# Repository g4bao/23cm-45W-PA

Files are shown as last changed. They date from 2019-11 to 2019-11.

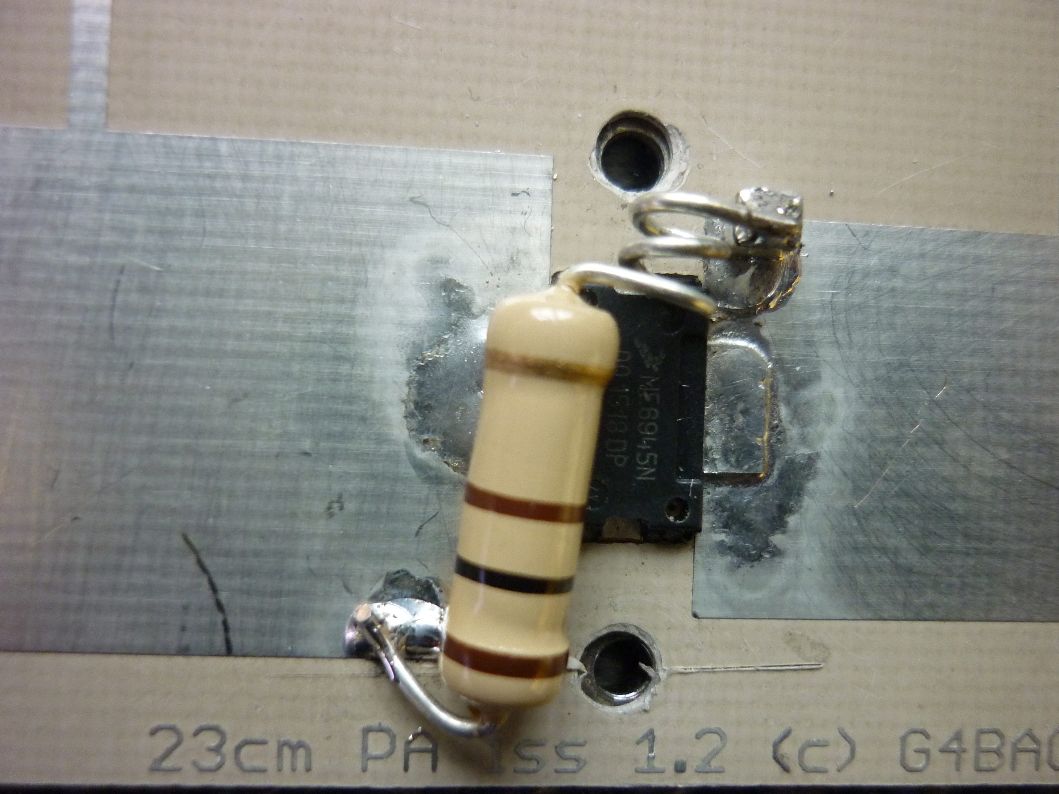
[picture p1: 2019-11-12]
Feedback.JPG

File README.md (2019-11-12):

# 23cm-45W-PA
This repository contains details of the G4BAO 45Watt 23cm Power Amplifier published in RSGB RadCom Magazine in June 2009 and later in the book " Microwave Know How for the Radio Amateur" by Andy Barter, G8ATD

This PA was sold for many years as a kit by the designer. The decision has been made to not sell any further kits so the designs are now made avaialable here under the terms of an MIT licence. 
It includes a copy of the original article, Eagle board and schematic files, plus Gerber files for the PCB, which must be made from  Taconic 0.7mm RF35 substrate.

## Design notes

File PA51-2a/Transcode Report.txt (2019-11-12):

   ---- Transcoding 'F:\Eagle files\projects\23cms PA\Gerbers\PA51-2a\PA51-2a.cmp' ----   Wed Nov 04 16:26:55 2015

D10   --> D100
D11   --> D101
D12   --> D102
D13   --> D103
D14   --> D104
-----------------------------------------------------------------

   ---- Transcoding 'F:\Eagle files\projects\23cms PA\Gerbers\PA51-2a\PA51-2a.pls' ----   Wed Nov 04 16:27:10 2015

D10   --> D105
-----------------------------------------------------------------

   ---- Transcoding 'F:\Eagle files\projects\23cms PA\Gerbers\PA51-2a\PA51-2a.sol' ----   Sat Nov 07 08:40:12 2015

D10   --> D100
D11   --> D101
D12   --> D102
D13   --> D103
D14   --> D104
-----------------------------------------------------------------

   ---- Transcoding 'F:\Eagle files\projects\23cms PA\Gerbers\PA51-2a\PA51-2a.pls' ----   Sat Nov 07 08:43:06 2015

D10   --> D105
-----------------------------------------------------------------

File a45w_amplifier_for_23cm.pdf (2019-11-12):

RADCOM ♦ JUNE 2009 | DR JOHN C WORSNOP, CENG, MIET, G4BAO ♦ E-MAIL: JOHN@G4BAO.COM | TECHNICAL FEATURE

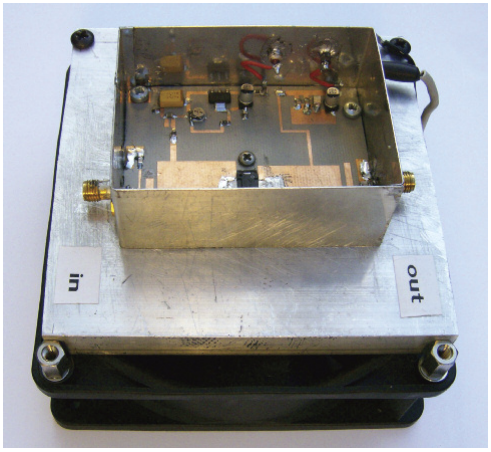
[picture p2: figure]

INTRODUCTION. For many years I operated on 23cm with just 2 watts RF output but never experienced the aircraft scatter and consistent over-the-horizon contacts that I knew the band could support. Increasing the power by 13dB or so opened up the band in ways I didn’t think possible. This article

describes a 45W Class
AB Power amplifier
covering the 1.3GHz
band that requires only
a few watts of drive for
full output. It is a
modern, safe
replacement for a single
2C39A valve amplifier
and does not require a
hazardous high voltage
power supply. It is ideal
for use with a DB6NT
or similar transverter,
a Kenwood TS2000X
or similar transceiver,
reaching a power level
where the 1.3GHz band becomes interesting. The design is very simple and based around a single Freescale [1] MRF9045 28 volt LDMOS device. The PCB is designed to fit in to a readily available 72 x 55 x 30mm tinplate box [2], and should be bolted to a suitable large, heatsink. Alternatively, a smaller heatsink with a fan can be used, as shown in Photo 1. A mini kit consisting of the PCB and MRF9045 is available [3]. This project uses small surface mount devices and requires some experience to construct and set up. It is therefore not suitable for novice constructors.

CIRCUIT DESCRIPTION. Researching designs for the MRF9045 and similar devices it seemed that matching these devices to 50Ω at 1.3GHz requires a relatively simple microstrip network with low impedance (ie wide) lines on the input and output. Half a day playing with Appcad [4] and a Smith chart program [5] allowed me to get a reasonable handle on the required matching networks.
Figure 1 shows the complete circuit diagram. In order to reduce losses, the final circuit avoids using trimmers and shunt capacitors. Device input and output impedances are matched to 50Ω using series low impedance lines TRL2, 4 and 5. ‘Shunt’ lines facilitate the final tuning. The open circuit shunt lines TRL3, TRL6 perform the function of the shunt capacitors of lumped element designs and there is a short circuited shunt line on the input, TRL1, grounded at the end by C5.
The 28 volt supply is connected to the drain via an isolating quarter wave high impedance line, TRL7 and decoupled over a wide range of frequencies by C3, C4, C5 and C6.
Positive gate bias is fed via a similar high impedance line, TRL8, from a 5V regulator and potential divider to set the standing drain current to 350mA. The gate supply is decoupled by C7, C8 and C10. The connection to the gate is via ‘stopper resistor’ R1. This is essential to the design, as it vastly improve low frequency stability of the amplifier. LDMOS devices are remarkably robust but they are susceptible to too much gate voltage. The only time I've destroyed a device during development is when I omitted this resistor. Without gate bias the amplifier takes very little current. Switching the 5V regulator from the press to talk (PTT) line is a convenient way to switch the amplifier in and out of standby, minimising standby power consumption and heat generation.

CONSTRUCTION. The PA is built on a special 0.8mm thick low loss Teflon PCB, the

# A 45W amplifier for 23cm

# LDMOS technology offers easy and

economical microwave power.

PHOTO 1: A prototype 23cm power amplifier fitted to small aluminium heatsink with fins running horizontally. A small black fan gives enough airflow to keep the heatsink cool (Photo: Colin, G8LBS).

TABLE 1 - COMPONENT LIST

Component Value | Type | Farnell reference
R1, R3, R4 820Ω | SMD 0805 | 9334890
R2 | 10k | SMD preset | 1173884
C1, C2, C3 100pF | Np0 ceramic 0805 1414655
C8 | 47pF | Np0 ceramic 1206 1414734
C11 | 47pF | Np0 ceramic 0805 1414692
C4, C7 | 1nF | Np0 ceramic 0805 718567
C5, C9 | 10µF 35V | SMD electrolytic | 8823120
C6 | 100nF | X7 ceramic 0805 | 9406387
C10 | 47µF 16V | SMD electrolytic | 498762
U1 | MRF9045 | LDMOS power FET | www.g4bao.com
U2 | TS2937CW SMD 5V regulator | 7261365
TRL1-8 | Microstrip matching lines on PCB

TECHNICAL FEATURE | JUNE 2009 ♦ RADCOM

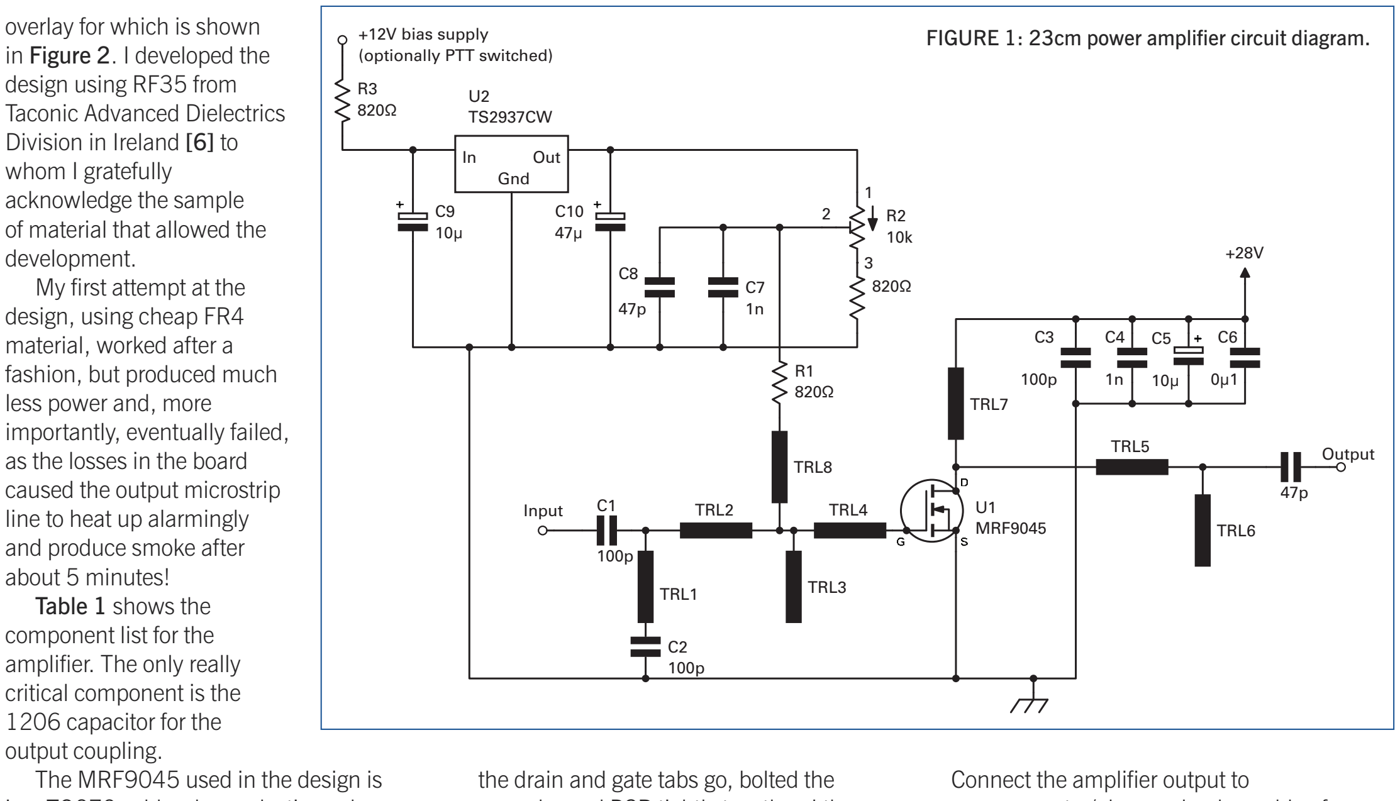
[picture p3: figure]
overlay for which is shown in Figure 2. I developed the design using RF35 from Taconic Advanced Dielectrics Division in Ireland [6] to whom I gratefully acknowledge the sample of material that allowed the development. My first attempt at the design, using cheap FR4 material, worked after a fashion, but produced much less power and, more importantly, eventually failed, as the losses in the board caused the output microstrip line to heat up alarmingly and produce smoke after about 5 minutes! Table 1 shows the component list for the amplifier. The only really critical component is the 1206 capa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

in a TO270 solder-down plastic package. These are now becoming more popular and eliminate the need for hazardous beryllium oxide in the package.
The device is soldered to a piece of copper plate approximately 27mm square and 1mm thick, which acts as a heat spreader between the MRF9045 and the heatsink. (Actually I used one face cut from a piece of waveguide 16). The spreader is soldered to the underside of the PCB and has two holes drilled in it to allow the spreader to be bolted to the heatsink.
Applications note AN1907 [7] from Freescale gives very strict guidelines on temperatures for soldering these devices but I thought, "what the heck, I can’t afford a soldering oven, but I can afford to sacrifice
a couple of devices if it doesn’t work". So I tinned the underside of the PCB, the mating surface of the spreader and the topside where spreader and PCB tightly together. I then dropped the module, spreader side down, on the kitchen ceramic hob, turned it on
and waited for the solder to melt. It duly
did, leaving a shallow ‘pool’ of solder in the rectangular hole in the PCB. I carefully placed the device into the hole, pressing down with the tweezers. I then quickly slid the module off the heat, keeping the pressure on the device until the solder set. Once the device is fitted you can solder in the other components. I have used this technique many times now with no ill effects on the devices. If you have a proper hotplate, all the better; I have now gone ‘upmarket’, using an old dry clothes iron, that I clamp upside down in a vice; that does the trick just as well.
No special precautions or techniques are required for fitting the other components, apart from good microwave practice. Be particularly careful to avoid excess solder, whiskers or excessive flux residues as these can
affect performance.

ALIGNMENT. Bolt the
assembled board and
heat spreader to a large
heatsink. The input and
output matching tabs are
split so that you can
lengthen or shorten them
by bridging them with
solder, if necessary. Start with all the tabs linked for maximum length.
Connect the input from
your 1.3GHz transmitter to the amplifier input via a
suitable SWR meter.

a power meter/ dummy load capable of dissipating and measuring at least 50W. Connect the drain to 28 volts via an ammeter on the 1A range. Connect the gate bias supply, starting with minimum volts on the gate and very carefully increase the gate voltage until the device begins to take current. This onset is very sharp, so be very careful, as the drain current can easily swing up to many amps if you are not careful. Set the drain current to 350mA. Switch off power and then switch the ammeter to the 10A range. Switch back on. Apply 0.5W drive and check the input VSWR. It should be better than about 1.7:1.
If the input VSWR and output power are about right you’re finished, so leave well alone! If not, switch off. Remove one section of one input tab at a time until the VSWR is less than 1.7:1 and check the output power and current. If necessary, trim the output tabs in the same way for maximum power. Do NOT try to make these adjustments with the amplifier operating. Turn up the drive in 3dB steps to 2W and check that the power increases about 3dB each time until it saturates. Now trim the output tab for minimum current consistent with maximum output power. It goes without saying, I hope, that you disconnect both the drain and source bias supplies before you trim the tabs.

RESULTS. Test results for a prototype amplifier are shown in Figures 3 and 4.

CONCLUSIONS. This is an inexpensive PA and is relatively easy to build, with readily available components and produces a useful increase in output power for transverters and transceivers.

FIGURE 1: 23cm power amplifier circuit diagram.

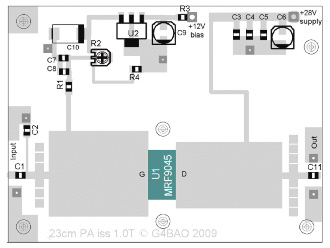
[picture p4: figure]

FIGURE 2: PCB overlay.

RADCOM ♦ JUNE 2009 | TECHNICAL FEATURE

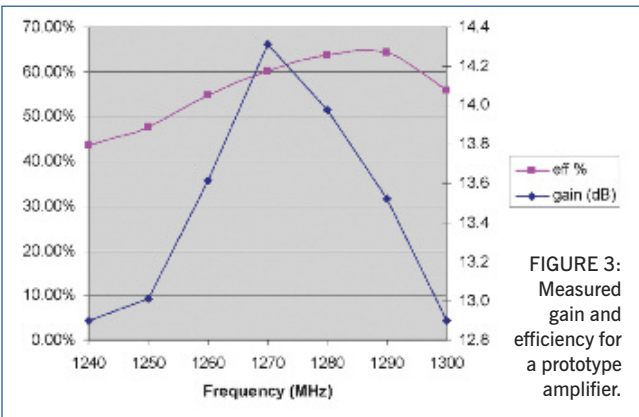
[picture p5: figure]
FIGURE 3: Measured gain and efficiency for a prototype amplifier.

It is efficient and it is safe, in that it does not use any hazardous high voltage supplies. Note, though, it will give you a nasty RF burn if you are silly enough to poke your finger on the output line while transmitting.
It covers the whole of the 1.3GHz narrow band section and, with careful retuning (tabbing), could be adapted to cover the 1240MHz section of the band if band planning eventually forces a move of 1.3GHz narrowband lower in the band.
The amplifier can be made small enough to be masthead mounted, particularly if a fan is fitted, or with a bigger heatsink can be silent for shack use.

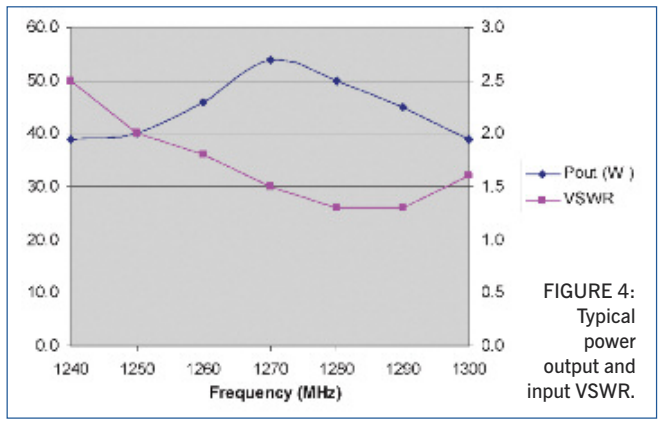
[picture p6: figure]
FIGURE 4: Typical power output and input VSWR.

DEVICE AND PCB AVAILABILITY. A colleague in the US was lucky enough to find a source of ‘new old stock’ MRF9045 LDMOS power transistors in sufficient quantity to make it possible to offer them to constructors. These devices and a PCB will be available shortly, see [3]. I strongly recommend that you do not attempt to make your own PCB, particularly on FR4 laminate, due to the likelihood of catastrophic board failure.

REFERENCES
[1] Freescale applications note AN1907, www.freescale.com/files/rf_if/doc/app_note/ AN1907.pdf
[2] Suitable tinplate boxes can be obtained
from Alan Melia, G3NYK at
www.alan.melia.btinternet.co.uk/componen.htm
[3] PCBs and MRF9045 devices will be available in Europe from www.g4bao.com, and in the Americas from www.wa5vjb.com.
[4] A free and fully functional copy of ‘Appcad’ can be downloaded from www.hp.woodshot.com/ appcad/appcad.htm.
[5] A demo version of ‘Smith’ can be downloaded from www.fritz.dellsperger.net/downloads.htm
[6] Taconic International, Advanced Dielectrics Division, Mullingar Business Park, Mullingar, Co. Westmeath Tel: 00353 (0) 44 9339071, e-mail: add@4taconic.com; www.taconic-add.com
[7] Freescale applications note AN1907, “Solder Reflow Attach Method for High Power RF Devices in Plastic Packages”

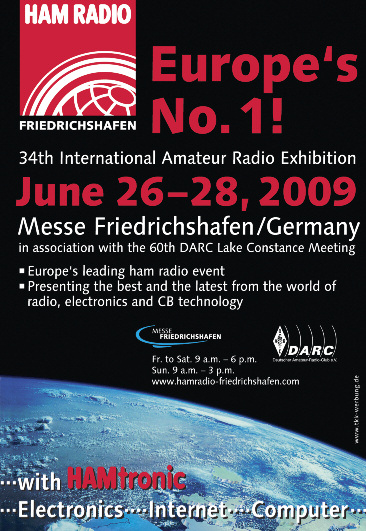
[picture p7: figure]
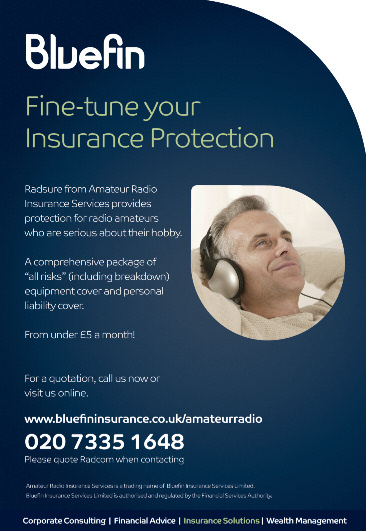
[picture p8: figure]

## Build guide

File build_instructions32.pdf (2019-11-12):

G4BAO 23cm PA build | Issue 3.21 November 2015

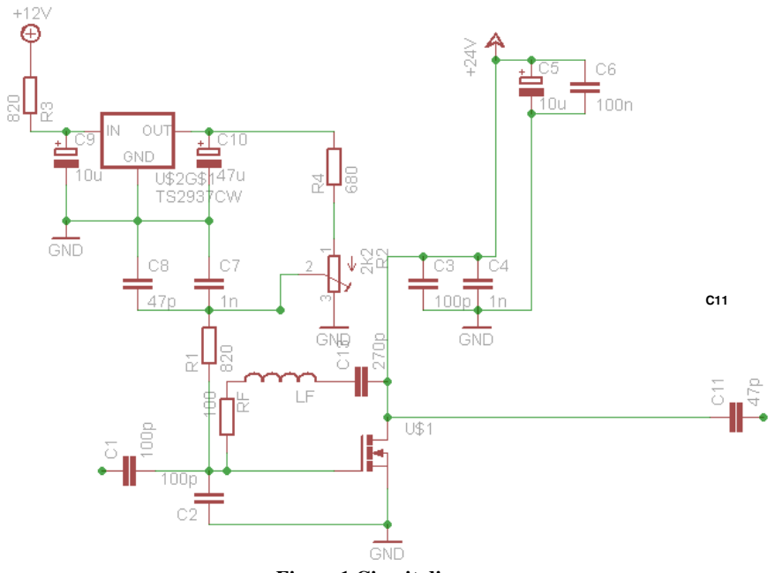
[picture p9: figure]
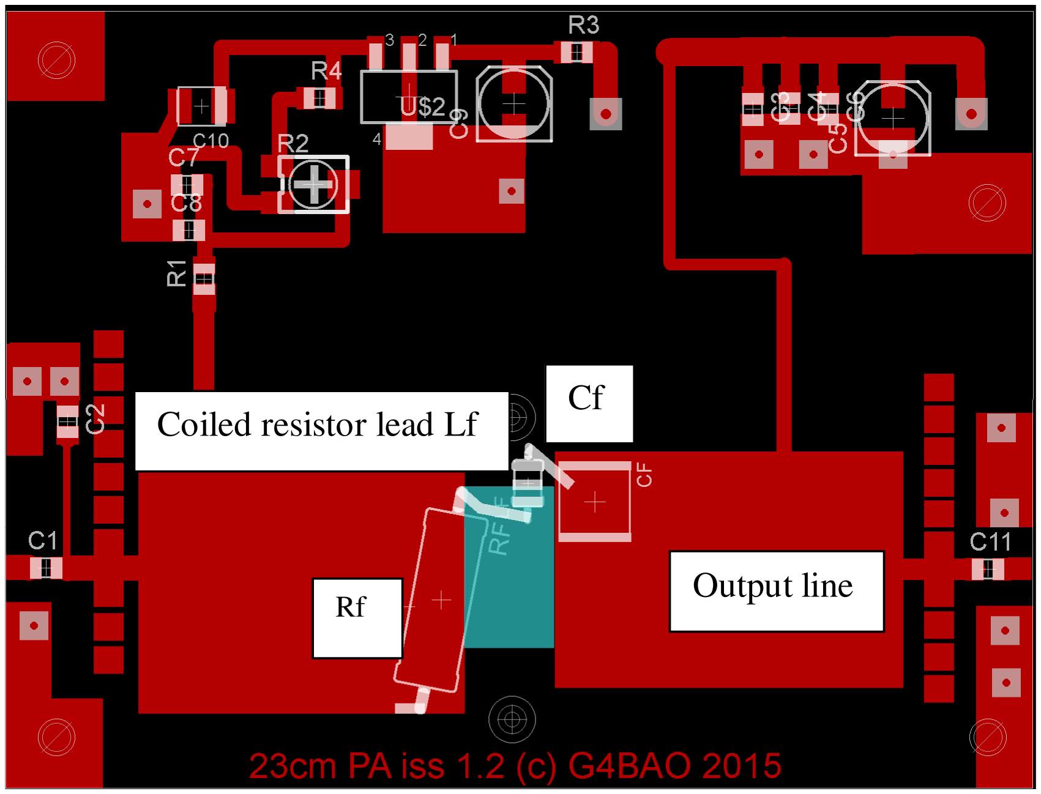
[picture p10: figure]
Coiled resistor lead Lf; Output line

© 2010 Bravo Alpha Oscar | Page 1 | printed 19/12/2015

# 23cm LDMOS Power Amplifier – Assembly notes

This kit contains the components required to build a G4BAO 23cms Power amplifier as described in the June 2009 Issue of RadCom, and includes any updates since publication, particularly the feedback modification, Rf, Cf and Lf. Note that in the original article, the component sizes for C8 and C11 were transposed. Also the names of C5 and C6 have been transposed on the layout diagram. Looking at the board with the 28V pin to the top right, from left to right it goes in increasing value, C3 100pF, C4 1nF, C6 100nF, C5 (electrolytic) 10uF. This document is correct for PCBs purchased after November 15th 2015.

Figure 1 Circuit diagram

Figure 2 PCB layout

© 2010 Bravo Alpha Oscar | Page 2 | printed 19/12/2015

## Antistatic precautions

Note that the LDMOS power FET device fitted to the PCB is still susceptible to static damage until the board has been assembled. Do not remove the tinfoil from the PCB without wearing an antistatic wrist strap or at minimum before having first touched something grounded.

## Component list

Component | Value | Type | Identifier
R1, R3 | 820 | SMD 0805 | Red
R4 | 680 | SMD 0805 | Brown
R2 | 10k | SMD preset | The only preset in the kit!
Rf | 100 ohm | 2 Watt carbon film | Wire ended non- SMD part
C1, C2, C3 | 100pF | Np0 ceramic 0805 | Black and white
C11 | 47pF | Np0 ceramic 1206 | Black and clear plastic
C8 | 47pF | Np0 ceramic 0805 | Green
C4, C7 | 1nF | Np0 ceramic 0805 | Orange
C5, C9 | 10uF 35V | SMD electrolytic | Silver can. Black bar is negative
C6 | 100nF | X7 ceramic 0805 | No marking
C10 | 22 to 47uF 16V OR 10V | SMD Tantalum | Yellow case. Red bar is positive OR Black case, silver bar is positive
Cf | 270pF to 1nF | AVX RF cap | 271 large cube
Lf | | 2 turns of resistor Rf lead on 2.5mm mandrel | Part of Rf
U$1 | MRF9045 or similar | LDMOS power | Attached to PCB
U$2 | 78M05 | SMD 5V regulator | Manufacturer’s mark
PCB pins | Qty 2 | PCB pins | For +12 and +28Volt supplies
Wire | 100mm | 24SWG tinned copper | For tuning.

Check that all the components are present in the kit, and email john@g4bao.com immediately if there is anything missing.

## Tools

Use a small temperature controlled, earthed soldering iron, and thin (28swg) solder. A pair of small sharp side cutters
Small SMD tweezers

## Assembly

Remember throughout assembly that the FET is already fitted to the board so observe antistatic precautions.
The Teflon PCB material is softer that the usual FR4, so do not to bend the PCB once the components are fitted as this can crack the components
For best results, always use the preferred Schuberth tinplate box and follow the assembly notes carefully.

To fit the recommended standard Schuberth box, you just need to "nick" the two diagonal opposite corners of the board to accommodate where the box sides overlap internally.

© 2010 Bravo Alpha Oscar | Page 3 | printed 19/12/2015
1. Fit the +12 and +28Volt pins, soldering top and bottom. They are a tight push fit in to the holes. Take great care to ensure that you do not bridge the solder to ground, especially underneath.
2. Link the all the input and output tuning tabs. Refer to Fig 3 showing how to do this. Put a small blob of solder on all tabs first then tin the end 2mm of the link wire and solder it between the tabs. Then trim the wire off with a sharp scalpel. Do this for each pait of tabs and the input/output lines.
3. Check for shorts to ground on the +12 and +28volt pins Fit the two resistors R3 and 4. DO NOT FIT R1 YET!
4. Fit the eight 0805 ceramic capacitors C1-4, C6, C7, C8, C11.
5. Fit the Preset R2
6. Fit C5, C9 and C10.
7. Fit the 5V regulator.
8. Fit the feedback components RF and Cf as described below
9. Stick a small piece of insulating tape underneath the supply pins, as the solder bulge puts them close to the heatsink when bolted down.

Use exactly the same layout as shown in Photo 1 or poor results will be obtained.
Stand the AVX capacitor “on it’s end” and solder the bottom to the output line first. Tin the other end. The resistor comes ready trimmed and should fit between the input line and the top of the capacitor. Solder the resistor short leg down first, then carefully bend the “coil” end such that it touches the unattached end of Cf. Make sure that the coil lead stays touching the capacitor, and does not “pull” on the end of the capacitor after soldering as it could break it once soldered. You can then solder it to the unattached end of Cf.

Make sure that the coil turns are not shorted, and that neither the capacitor nor the coil shorts to ground, the screws or the PA transistor.

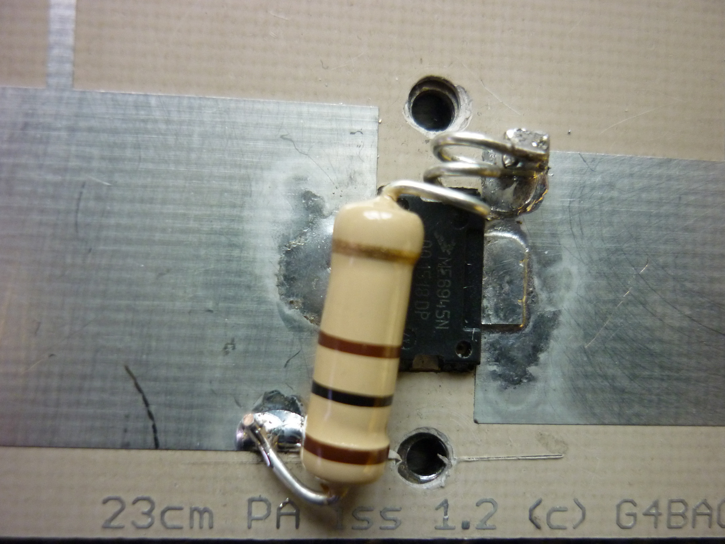
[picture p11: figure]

© 2010 Bravo Alpha Oscar | Page 4 | printed 19/12/2015

## Initial check

RE-CHECK THAT YOU HAVE NOT FITTED R1 YET. If you have, remove it and place it to one side for later!

Be careful with R2, it is possible to increase the bias enough to destroy the device Turning the pot clockwise INCREASES the Bias current/voltage

Check for shorts to ground on the +12 and +28Volt pins

Set R2 to the centre of its travel and apply +12 volts to the 12volt pin, and ground to the ground plane and measure the voltage at the + end of C10. It should read 5 volts +/- 0.2.

Measure the voltage at the junction of C8 where it connects to R1. It should be 2.3V +/- 0.2.

Rotate R20 anticlockwise until the voltage is at minimum. Measure the voltage at the junction of C8 where it connects to R1. It should be 0.0V +/- 0.2.

Leave the preset at this setting and remove the 12 volt supply. Fit R1.

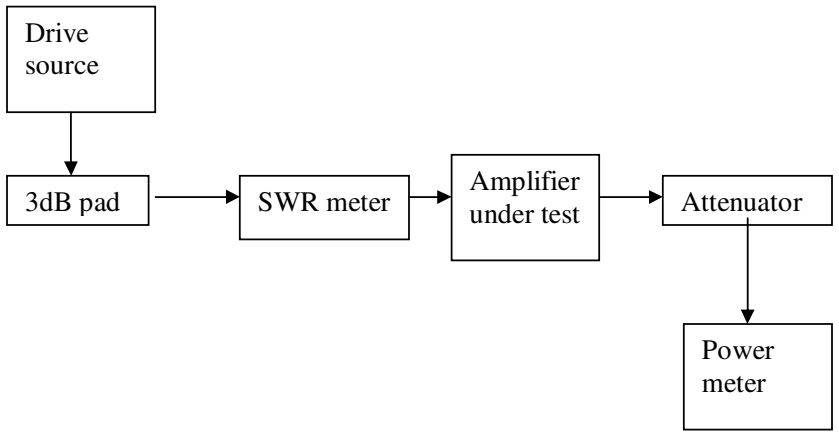
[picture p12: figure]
Drive source; 3dB pad; SWR meter; Amplifier under test; Power meter; Attenuator

© 2010 Bravo Alpha Oscar | Page 5 | printed 19/12/2015

## Recommended Test equipment

Equipment | Example
1.3GHz SWR meter | Bird Thruline or Diamond SX1000
Drive source with adjustable power from 0.5 to 3W | Transceiver/ transverter plus 3dB attenuator
RF power meter and attenuators to measure up to 50Watts | HP 435A, HP436 plus 30 dB attenuator. Bird Thruline or Diamond SX1000 plus 50Watt dummy load.

## Assembly notes

If you are mounting the PCB in the recommended tinplate box, make sure that the tabs for the input and output connectors do not short to the box. If so trim them back 0.5mm with a very sharp scalpel
Where possible align the PCB in its final box to minimise tuning errors due to proximity of the box sides effecting tuning. If using the recommended the Eisch/G3NYK boxes, the PCB should be fitted such that the bottom of the heat spreader plate is flush and level with the bottom of the box sides. This allows the whole box and PCB assembly to be bolted flat on a heatsink using the two screws through the heat spreader. I’ve found that no other fixings are needed. Solder the edges of the ground plane and the topside grounds near input and output to the tinplate box completely round the ground plane side. The two SMA connector centres should be mounted 6mm up the box sides to allow for the SMA plugs to be screwed on. The SMA centre spills should be connected to the PCB with the shortest length of 0.5mm copper wire possible.

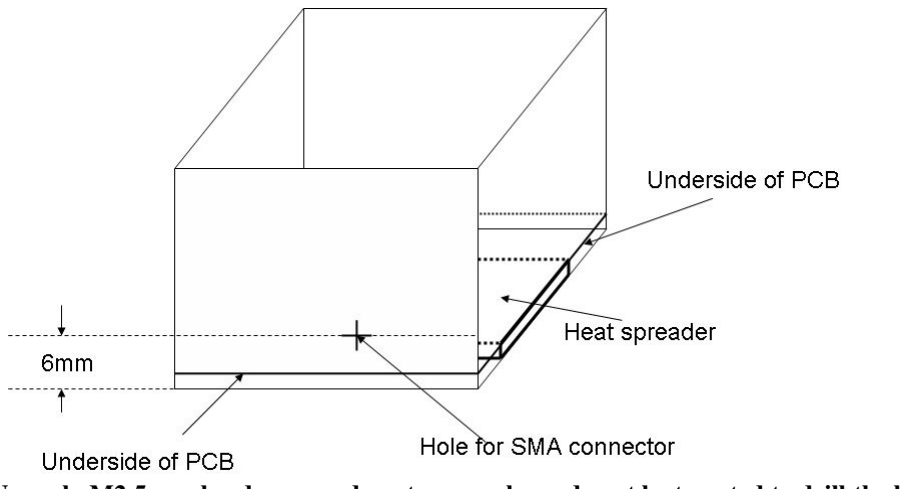
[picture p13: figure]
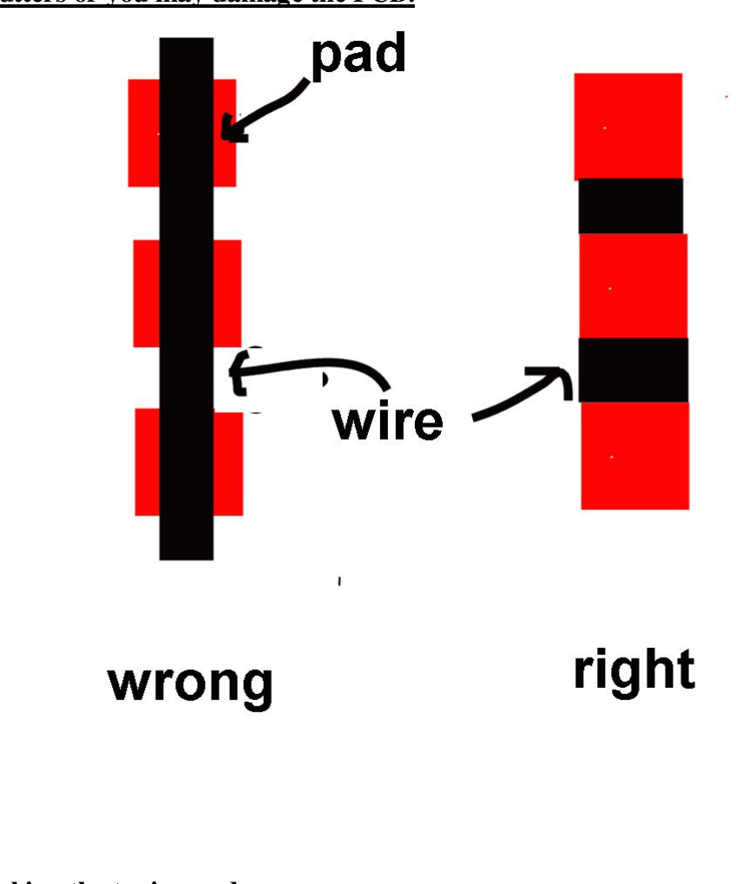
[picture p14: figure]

© 2010 Bravo Alpha Oscar | Page 6 | printed 19/12/2015

Use only M2.5 pan head screws, do not use washers, do not be tempted to drill the holes bigger and use M3 or the heads will short to the matching lines. Bolt the assembled board and heat spreader to a large heatsink

## Alignment

The input and output matching tabs are split so that you can lengthen or shorten them by bridging them with the 24SWG wire, if necessary. Start with all the tabs linked for maximum length, and remove one section of link wire at a time with a soldering iron when tuning, leaving the PCB track in place so you can revert back if necessary.
Note that you should link the pads as shown in Figure 3 linking the tuning pads and only remove them with a soldering iron. Do not be tempted to link them the “wrong” way and remove them with side cutters or you may damage the PCB.

Figure 3 linking the tuning pads

© 2010 Bravo Alpha Oscar | Page 7 | printed 19/12/2015

Connect the input from your 1.3GHz transmitter to the amplifier input via a suitable 23cm SWR meter. (Bird Thruline, diamond SX1000) Connect the amplifier output to a power meter/ dummy load capable of dissipating at least 50Watts. If you are using “flying coax leads” to connect rather than a box and connectors, there should be NO braid tail, not even 1mm. Use thin PTFE coax so that the inner does not melt and solder the braid directly to the convenient ground point close to the input and output pads. Connect the drain to 28 volts via an ammeter on the 1 amp range. Connect the gate bias supply, starting with minimum volts on the gate and VERY carefully increase the gate voltage (remember, clockwise) until the device begins to take drain current. This onset is very sharp, so be very careful, as the drain current can easily swing up to many Amperes if you are not. Set the drain current to 350mA +/-5mA. This may rise by some 50mA as the device warms up, this is normal. Switch off both supplies and then switch the ammeter to the 10 Amp range. Switch back on.

Check all your connections take a deep breath and apply 0.5 watts drive. Check the input VSWR. It should be better than about 1.7:1. Remove one section of one input tab at a time until the VSWR is less than 1.7:1 and check the output power and current. Once you have minimised the VSWR, trim the output tabs in the same way for maximum power and efficiency. Note that you may not have to remove ANY Tabs. Turn up the drive in 3dB steps to 2 Watts and check that the power increases about 3dB each time until it saturates. As you approach the correct output match, you will find that the amplifier saturates at a higher power. Trim the output tab and repeat until you get the maximum output power with around 3 amps drain current. It goes without saying, I hope, that you disconnect both the drain and source bias supplies before you trim the tabs. Remove the gate bias before the drain supply; reconnect the drain supply before the gate bias.
When all is well, for an input of 2 Watts maximum, you should expect an input VSWR of 1.5:1, or better and an output power of between 35 and 45 Watts and a drain current of around 3 Amperes. Some boards may produce more than this power but operation above 45Watts is not recommended.

## Fault finding

There are only few components on the board, so there is little to go wrong, and fault finding is relatively easy. If you fail to achieve something close to the values in the previous paragraph, carefully inspect all your solder joints, and check that you have not cracked or damaged any of the surface mount components or the Power FET. If you can get access to a microscope to do this, all the better! Recheck the bias current with no drive (standing current) It should not have changed by more than about 50mA. Measure the gate voltage and it should be in the 2.7 – 3.5 volt range. If the standing current has changed by more, and you cannot reset it to 350mA, chances are you have blown the device!

Low output power but the correct current could be due to a damaged (cracked) output capacitor C11 A poor input VSWR could be due to a damaged (cracked) input capacitor C1, or poor termination of the PCB input pad.
